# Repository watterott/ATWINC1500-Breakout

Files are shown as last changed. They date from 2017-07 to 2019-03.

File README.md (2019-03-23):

# ATWINC1500-Breakout
ATWINC1500-Breakout with Microchip WINC1500 WiFi Network Controller SoC and Microchip ATECC508A Crypto Authentication.

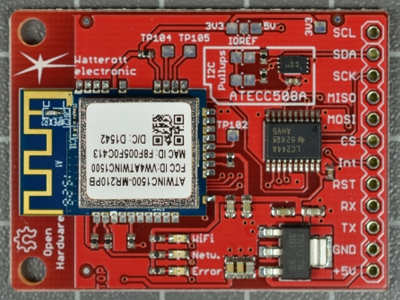
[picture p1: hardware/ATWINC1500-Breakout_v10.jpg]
ATWINC1500-Breakout


* [Microchip ATWINC1500B](http://www.microchip.com/wwwproducts/en/ATWINC1500) WiFi Network Controller (SPI)
* [Microchip ATECC508A](http://www.microchip.com/wwwproducts/en/ATECC508A) Crypto Authentication (I2C)
* Integrated WiFi and IPv4 stack
* 3.3V - 5V tolerant IOs
* Open-Source and released under the [Creative Commons Attribution Share-Alike License](https://creativecommons.org/licenses/by-sa/4.0/).
* **[Documentation on learn.watterott.com](https://learn.watterott.com)**

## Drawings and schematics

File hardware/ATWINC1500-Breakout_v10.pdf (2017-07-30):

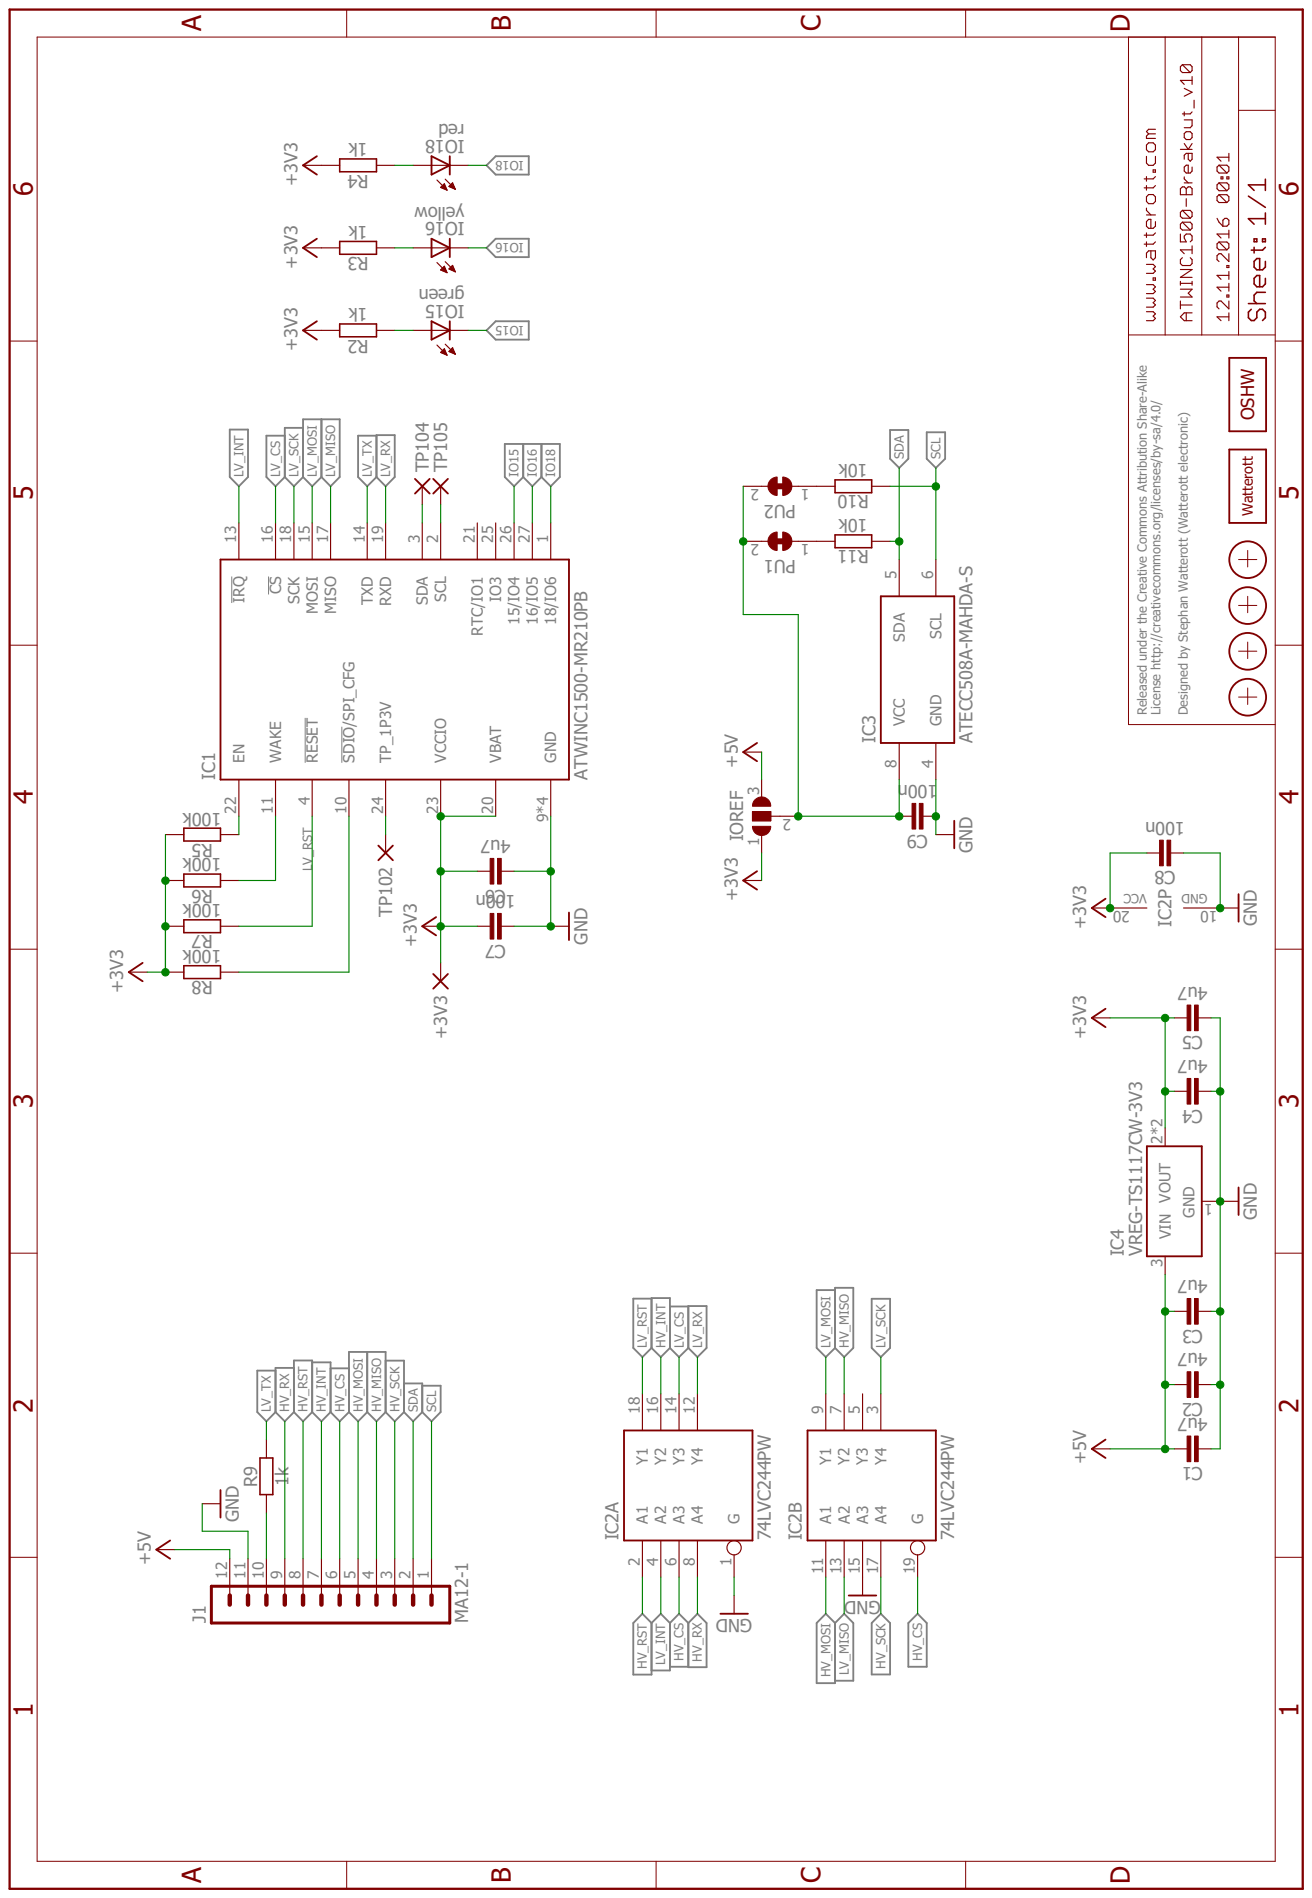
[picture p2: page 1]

woll ey k1 +3V3 der k1 +3V3 ATWINC1500-MR210PB VREG-TS1117CW-3V3 +5V +3V3 GND 7u4 7u4 7u4 7u4 neer g k1 +3V3 GND +3V3 k001 k001 k001 k001 +3V3 n001 7u4 74LVC244PW 74LVC244PW +3V3 GND DNG GND +3V3 +5V k01 n001 k01 1k n001 7u4 DNG +5V GND MA12-1 Released under the Creative Commons Attribution Share-Alike License http://creativecommons.org/licenses/by-sa/4.0/ Designed by Stephan Watterott (Watterott electronic) 61 OI 3R 81 OI 4R IC3 ATECC508A-MAHDA-S SCL 6 SDA 5 VCC 8 GND 4 16/IO5 27 SCL 2 SDA 3 RESET 4 GND 9*4 SDIO/SPI_CFG 10 WAKE 11 IRQ 13 TXD 14 MOSI 15 CS 16 MISO 17 SCK 18 RXD 19 VBAT 20 RTC/IO1 21 EN 22 VCCIO 23 18/IO6 1 IO3 25 15/IO4 26 IC1TP_1P3V 24 IC4 GND VIN 3 V1 OUT 2*2 2C3C4C5C 51 OI 2R 5R6R7R8R 7C6C IC2AG 1 A1 2 A2 4 A3 6 A4 8 Y4 12 Y3 14 Y2 16 Y1 18 IC2BG 19 A1 11 A2 13 A3 15 A4 17 Y4 3 Y3 5 Y2 7 Y1 9 IC2PCCV DNG 02 01 IOREF3 1 2 11R TP104 TP105 TP1028C 01R R9 9C 1C 1UP 2 1 2UP 2 1 +3V3 J1 198765432101112 HV_MOSI HV_MOSI HV_MISO HV_MISO HV_SCK HV_SCK HV_CS HV_CS HV_CS SDA SDA SCL SCL HV_RST HV_RST HV_INT HV_INT HV_RX HV_RX 81 OI IO18 61 OI IO16 51 OIIO15 LV_TX LV_TX LV_RX LV_RX LV_MISO LV_MISO LV_MOSI LV_MOSI LV_SCK LV_SCK LV_CS LV_CS LV_INT LV_INT LV_RST LV_RST ABCD 1 2 3 4 5 6 ABCD 1 2 3 4 5 6 Watterott OSHW

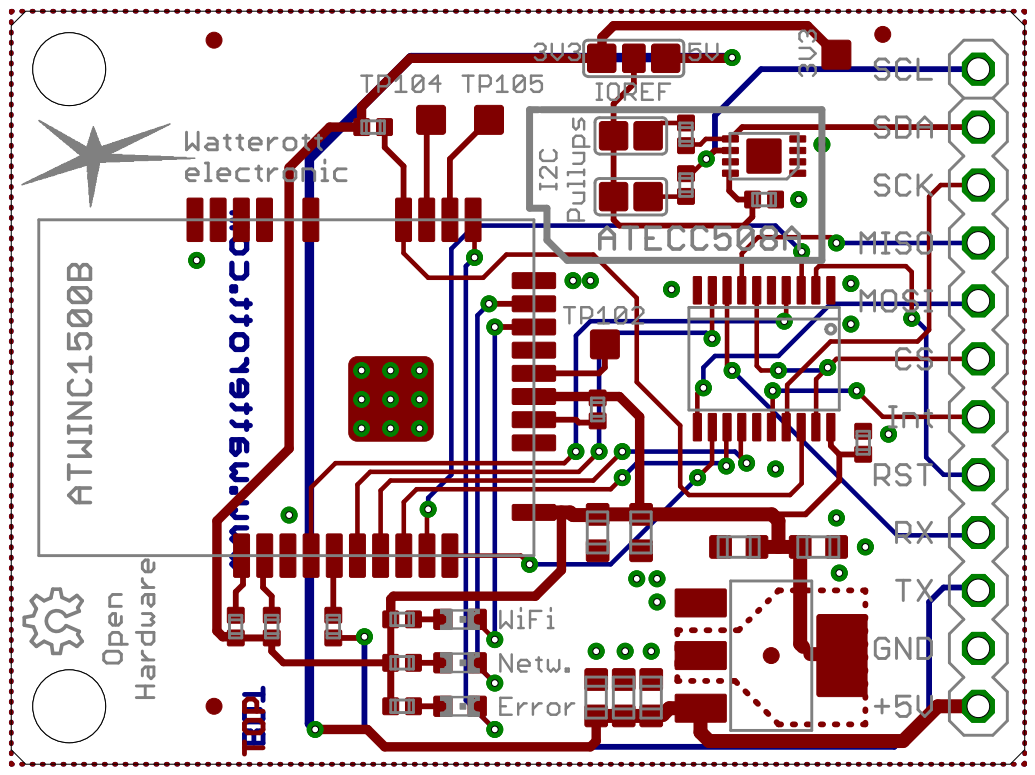
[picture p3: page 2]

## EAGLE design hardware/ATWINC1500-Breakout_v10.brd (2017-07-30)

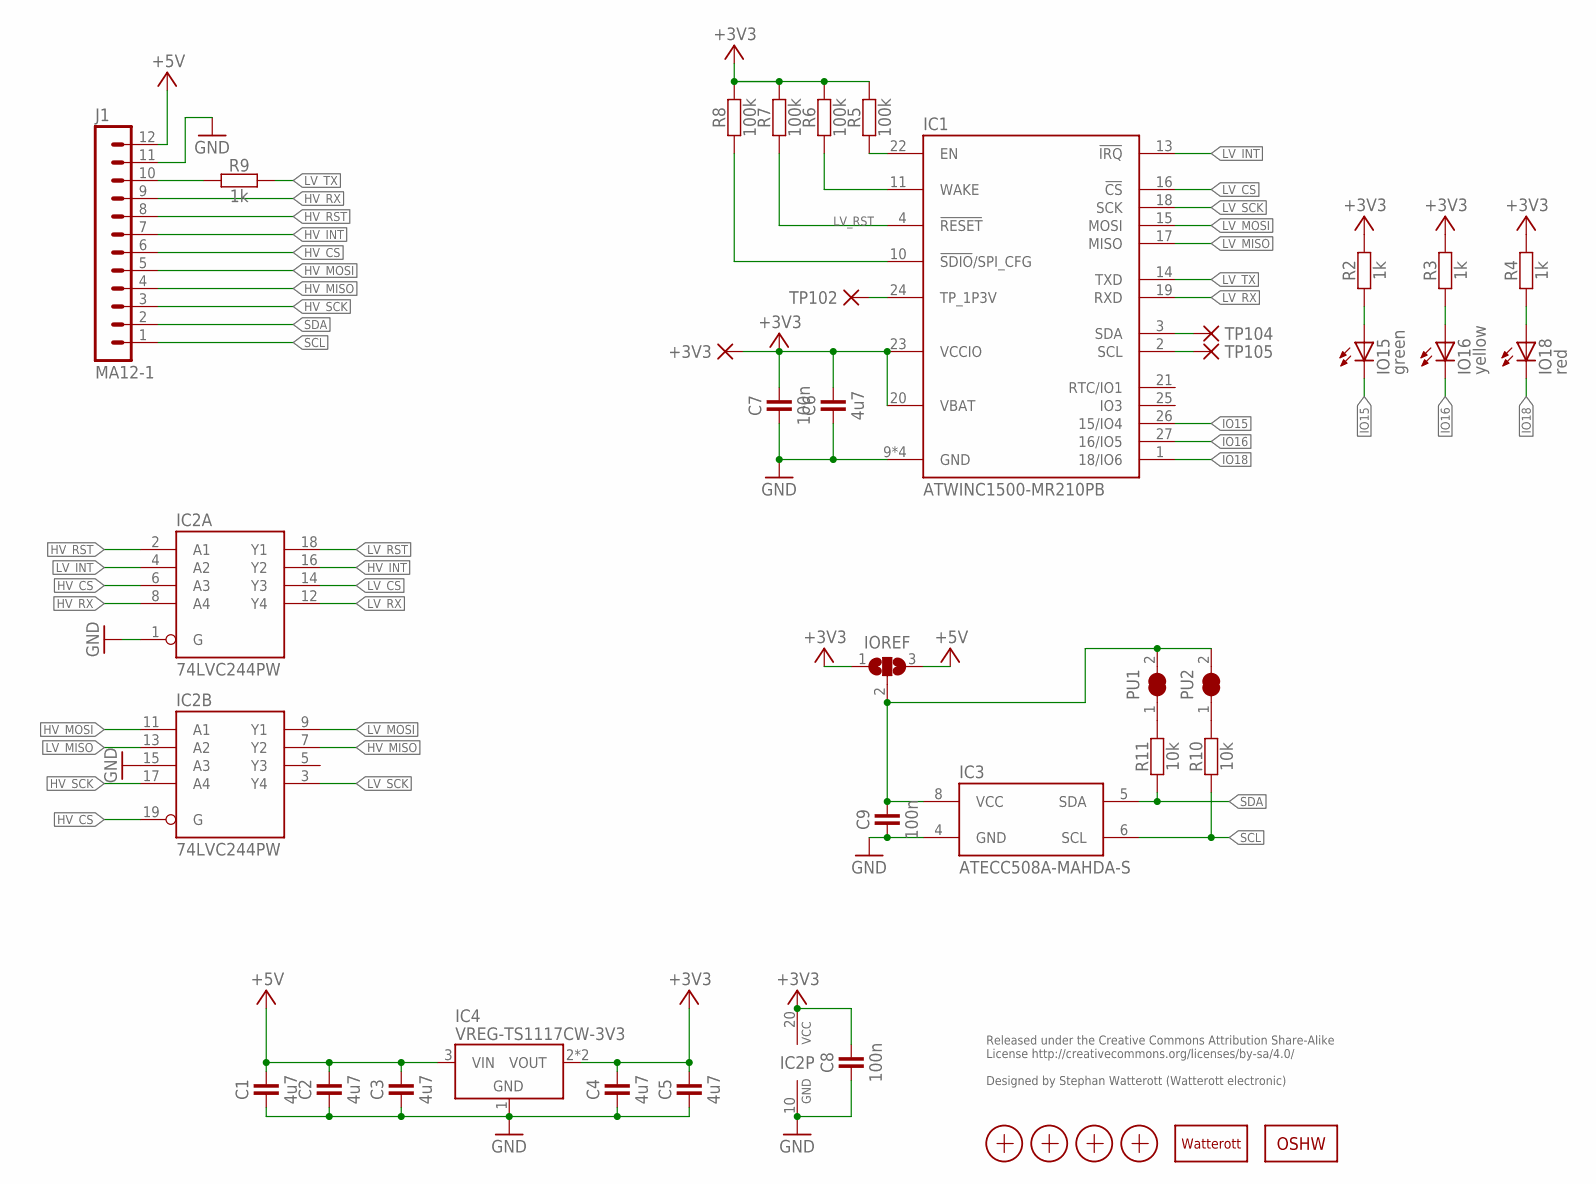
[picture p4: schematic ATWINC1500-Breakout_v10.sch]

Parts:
+3V3: PAD-1.27X1.27_NC
C1, C2, C3, C4, C5, C6: 4u7; C0603
C7: 100n; C0603
C8, C9: 100n; C0402
IC1: ATWINC1500-MR210PB; ATWINC1500-MX210
IC2: 74LVC244PW; TSSOP20
IC3: ATECC508A-MAHDA-S; UDFN8
IC4: VREG-TS1117CW-3V3; SOT223
IO15: green; C0603
IO16: yellow; C0603
IO18: red; C0603
IOREF: JUMPER3-0603-NC; JUMPER3-0603_NC
J1: MA12-1
LOGO1: LOGO-S_PLACE_M; SPARK_TPLACE_M
LOGO2: OSHW_LOGOX0100; OSHW_6X100
PU1, PU2: JUMPER2-0603-NC; JUMPER2-0603_NC
R2, R3, R4, R9: 1k; C0402
R5, R6, R7, R8: 100k; C0402
R10, R11: 10k; C0402
TP102, TP104, TP105: PAD-1.27X1.27_NC
X1, X2, X3, X4: PASSER-07; PASSER_07MM

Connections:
+3V3: +3V3.1, C4.2, C5.2, C6.2, C7.2, C8.2, IC1.20 (VBAT), IC1.23 (VCCIO), IC2.20 (VCC), IC4.2 (VOUT), IC4.4 (VOUT), IOREF.1, R2.2, R3.2, R4.2, R5.2, R6.2, R7.2, R8.2
+5V: C1.2, C2.2, C3.2, IC4.3 (VIN), IOREF.3, J1.12
GND: C1.1, C2.1, C3.1, C4.1, C5.1, C6.1, C7.1, C8.1, C9.1, IC1.9 (GND), IC1.12 (GND), IC1.28 (GND), IC1.GND, IC2.1 (G), IC2.10 (GND), IC2.15 (A3), IC3.4 (GND), IC4.1 (GND), J1.11
HV_CS: IC2.6 (A3), IC2.19 (G), J1.6
HV_INT: IC2.16 (Y2), J1.7
HV_MISO: IC2.7 (Y2), J1.4
HV_MOSI: IC2.11 (A1), J1.5
HV_RST: IC2.2 (A1), J1.8
HV_RX: IC2.8 (A4), J1.9
HV_SCK: IC2.17 (A4), J1.3
IO15: IC1.26 (15/IO4), IO15.C
IO16: IC1.27 (16/IO5), IO16.C
IO18: IC1.1 (18/IO6), IO18.C
IOREF: C9.2, IC3.8 (VCC), IOREF.2, PU1.2, PU2.2
LED15: IO15.A, R2.1
LED16: IO16.A, R3.1
LED18: IO18.A, R4.1
LV_CS: IC1.16 (!CS), IC2.14 (Y3)
LV_EN: IC1.22 (EN), R5.1
LV_INT: IC1.13 (!IRQ), IC2.4 (A2)
LV_MISO: IC1.17 (MISO), IC2.13 (A2)
LV_MOSI: IC1.15 (MOSI), IC2.9 (Y1)
LV_RST: IC1.4 (!RESET), IC2.18 (Y1), R7.1
LV_RX: IC1.19 (RXD), IC2.12 (Y4)
LV_SCK: IC1.18 (SCK), IC2.3 (Y4)
LV_TX: IC1.14 (TXD), R9.2
LV_WAKE: IC1.11 (WAKE), R6.1
unnamed: J1.10, R9.1
unnamed: PU2.1, R10.2
unnamed: PU1.1, R11.2
SCL: IC3.6 (SCL), J1.1, R10.1
SDA: IC3.5 (SDA), J1.2, R11.1
SPI_CFG: IC1.10 (!SDIO!/SPI_CFG), R8.1
TP: IC1.24 (TP_1P3V), TP102.1
WIFI_SCL: IC1.2 (SCL), TP105.1
WIFI_SDA: IC1.3 (SDA), TP104.1

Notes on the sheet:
Released under the Creative Commons Attribution Share-Alike License http://creativecommons.org/licenses/by-sa/4.0/ Designed by Stephan Watterott (Watterott electronic)

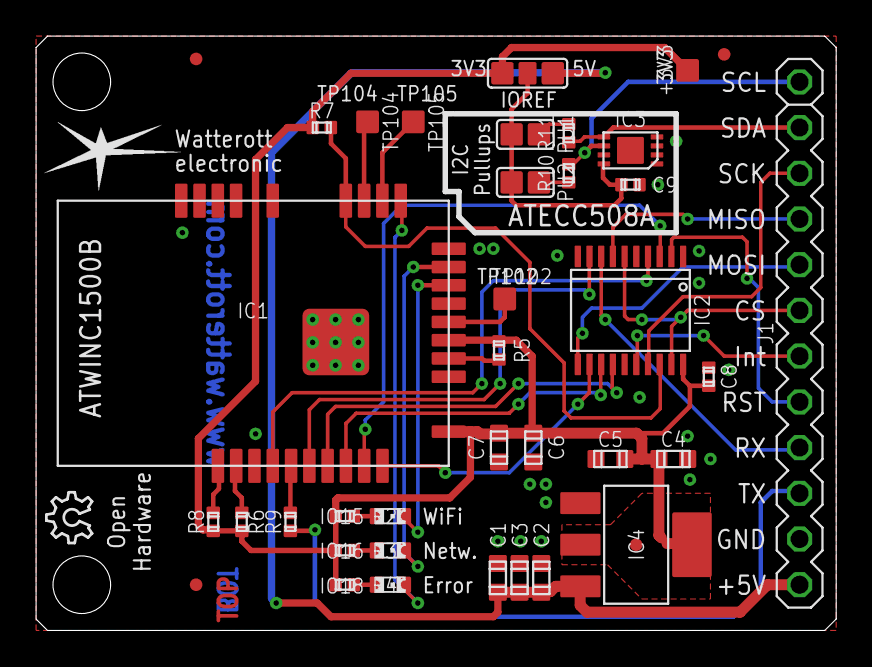
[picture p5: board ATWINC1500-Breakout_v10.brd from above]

Board: 2 copper layers, 44.5 x 33.0 mm, 40 parts (0 on the bottom side), 36 nets.
